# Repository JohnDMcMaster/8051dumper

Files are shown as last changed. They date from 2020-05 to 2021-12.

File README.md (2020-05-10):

# 8051dumper: Dump ROM contents from unprotected 8051 series processors.

This board and firmware allow the mask-programmed ROM contents to be dumped from
[Intel 8051 processors](https://en.wikipedia.org/wiki/Intel_MCS-51) and
derivatives/clones which do not include ROM readout protection mechanisms.

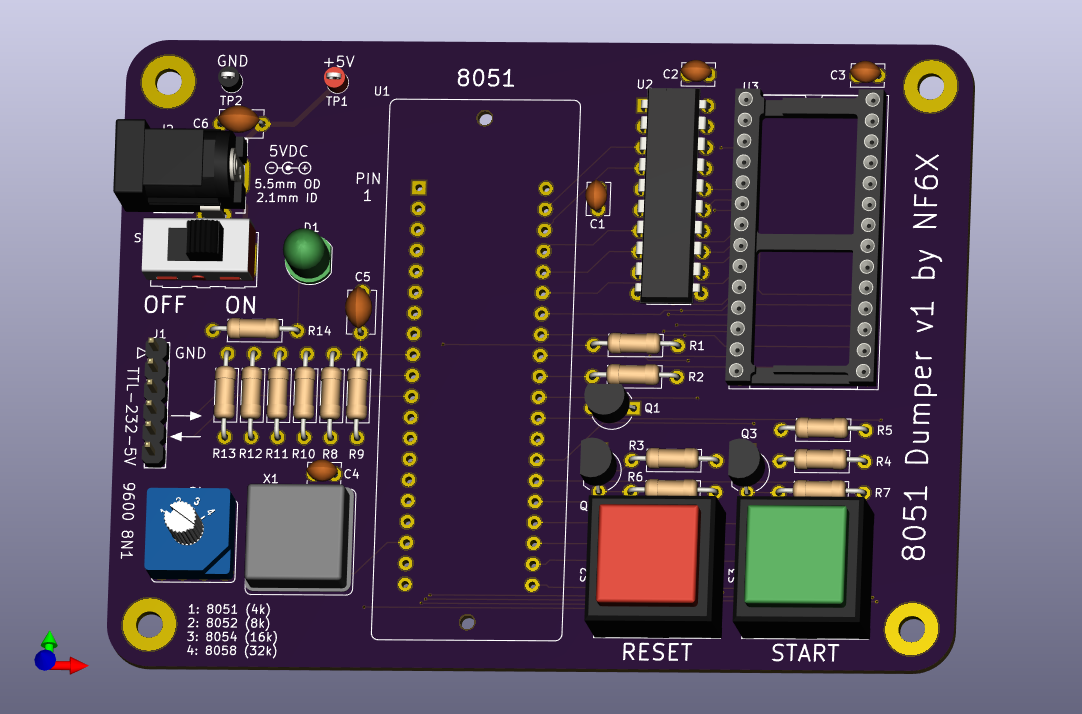
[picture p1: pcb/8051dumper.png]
8051dumper Render


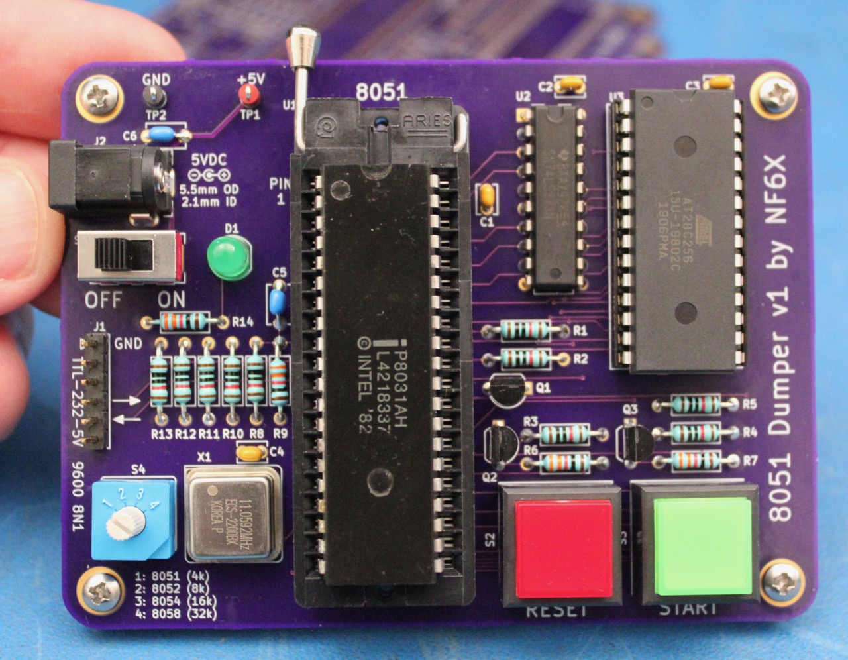
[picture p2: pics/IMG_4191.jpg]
First assembled 8051dumper board, with 8031 standing in for an 8051


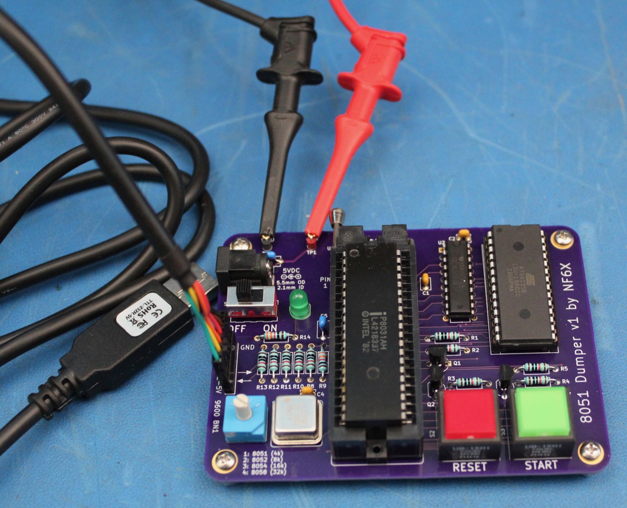
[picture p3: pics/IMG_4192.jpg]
8051dumper board with FTDI TTL-232R-5V cable connected, and power supplied with clip leads


## Description

I wanted to dump out the firmware from the internal mask ROM of a Signetics
SCN8051H microcontroller in an ailing Micropolis 1325 (AKA DEC RD53-A) hard disk
drive. None of my programmers are able to do that, but there's a tricky way to
get early 8051 microcontrollers to dump out their own firmware. I made this
board to do it... and over-engineered the heck out of it, because why not! This
technique has been around for a long time. I didn't invent it. I just made this
board because I'd rather lay out a board than wire up stuff on a breadboard.

The 8051 has a pin called EA\# which tells it whether to fetch code from its
internal ROM (which is programmed at the metal mask layer at chip fabrication
time) or an external ROM. The trick is to put the 8051 into a circuit which
initially pulls EA\# low, so that the 8051 will boot from an external ROM with
our dumper code in it. That code immediately jumps out of the 4k address range
that is mapped to internal ROM when EA\# is high, and then uses a GPIO pin to
pull its own EA\# pin high and re-enable the internal mask ROM. At that point,
the 8051 conveniently fetches program memory accesses in the 0x0000-0x0FFF range
from the internal ROM, and fetches program memory accesses outside that range
from our external ROM. The special dumper code on our external ROM can then use
the MOVC function to read internal ROM bytes, and then dump them out somehow
(such as with the built-in serial port).

The 8052, 8054 and 8058 chips have larger internal ROM spaces, but otherwise
work the same way. Just for the heck of it, I put a knob on this board to tell
its firmware how much of the internal ROM space it should try to dump.

Later 8051 derivatives added features to prevent dumping their internal ROMs
easily, sunce as simply latching EA\# at reset time so that changing it later
doesn't do anything. This board can't work with any of those. It's only intended
to work with original Intel 8051 microcontrollers and exactl clones whose EA\#
pins behave the same way.

## Building the Board

You're on your own for assembling the board. You will need to program the
board's firmware into an AT28C256 (or plug-in equivalent) 32k x 8 (E(E))PROM.
Use the `firmware/8051dumper_filled.hex` image. This image contains the
necessary firmware for the 8051dumper board, with its unused areas filled with a
recognizable pattern to help you identify whether any given device under test is
dumping internal or external ROM contents.

## Using the Board

This board requires an external source of clean, regulated 5 VDC power, and some
sort of asynchronous serial interface with 5V TTL/CMOS signal levels. An FTDI
TTL-232R-5V cable can be pluged right into the header, or you can use clip
leads. The silkscreen markings identify the ground pin and the two data pins.

**There is no reverse-polarity protection, power regulation, or overvoltage protection on this board.** You need to connect the power correctly, or you will fry stuff. You can supply power through either the barrel jack or with clip leads
connected to the two test points.

Set your serial interface for 9600 baud, 8 data bits, no parity, and no flow
control. Use a terminal emulator or any other suitable software which can
capture the 9600 baud stream from 8051dumper.

Always make sure that the power switch is **OFF** before installing or removing
a device under test from 8051dumper.

If all goes well, when you turn on the board with a working [8051 (or other
MCS-51 series)](https://en.wikipedia.org/wiki/Intel_MCS-51) microcontroller
installed, the green START button will begin blinking and the serial port will
spit out `8051dumper v1.0 by NF6X`. If that doesn't happen at power-on, try
pressing the red RESET button to reset the microcontroller manually. If it still
doesn't happen, start debugging. Maybe the socket isn't making good contact?
Maybe, well, literally anything else has gone wrong?

Once the green START button is blinking, set the knob to the appropriate ROM
size and then press the green START button to begin the dump. While the dump is
in progress, the red RESET button will flash rapidly. When the dump is done, the
red RESET button will go dark and the green START button will light up. Now you
can turn off the board, or press RESET to do it all over again.

The 8051dumper output is in [Intel hex](https://en.wikipedia.org/wiki/Intel_HEX)
format. If you try dumping beyond the end of the internal ROM, or if you try
dumping from a device which latches EA\# at reset time, then some or all of the
output will be from the 8051dumper's own external ROM instead of the device
under test's internal ROM. To help you indentify when this happens, the unused
spaces of 8051dumper's ROM are filled with a pattern which is recognizable in
either hexadecimal or ASCII representations, and repeats every 16 bytes:

* Address (2 bytes)
* 0x00
* 0x80
* 0x51
* 0x00
* "8051dumper"

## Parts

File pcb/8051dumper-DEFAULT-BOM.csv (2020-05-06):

MANUFACTURER | PARTNUM | QTY | REFS | IPN | VALUE | DESCRIPTION | FOOTPRINT | ALTERNATES
Aries | 40-6554-10 | 1 | U1 | TBD | 8051 |  | Package_DIP:DIP-40_W15.24mm_ZIF_Socket_Aries_40-6554-10
CK | 1101M2S3CQE2 | 1 | S1 | TBD | CK_1101M2S3CQE2 | SPDT slide switch, ON-ON | Button_Switch_THT:SW_CK_1101M2S3CQE2
CUI | PJ-050AH | 1 | J2 | TBD | CUI_PJ-050AH | DC Barrel Jack, 5.5mm OD x 2.1mm ID, through hole, w/ switch | Connector_BarrelJack:BarrelJack_Horizontal_CUI_PJ-050AH
Copal | S-2150 | 1 | S4 | TBD | Copal_S-2150 | Rotary switch, 4-position DIP 1P4T | Button_Switch_THT:Copal_S-2150
ECS | ECS-2200BX-110.5 | 1 | X1 | TBD | 11.0592 MHz | Crystal Clock Oscillator, DIP8-style metal package | Oscillator:Oscillator_DIP-8
Keystone | 5000 | 1 | TP1 | TBD | TestPoint_Mini_Red | Test point, 19x19mm 0.75x0.75in | TestPoint:TestPoint_Keystone_5000
Keystone | 5001 | 1 | TP2 | TBD | TestPoint_Mini_Black | Test point, 19x19mm 0.75x0.75in | TestPoint:TestPoint_Keystone_5001
Kingbright | WP7113GD | 1 | D1 | TBD | WP7113GD | Light emitting diode | LED_THT:LED_D5.0mm_Green_Kingbright_WP7113
Microchip | AT28C256-15PU | 1 | U3 | TBD | AT28C256-15PU |  | Package_DIP:DIP-28_W15.24mm_Socket
NKK | UB15SKG035C-CC | 1 | S2 | TBD | NKK_UB15SKG035C-CC | Momentary button, SPDT, red LED, square red lens | Button_Switch_THT:SW_NKK_UB15SKG035C-CC
NKK | UB15SKG035F-FF | 1 | S3 | TBD | NKK_UB15SKG035F-FF | Momentary button, SPDT, green LED, square green lens | Button_Switch_THT:SW_NKK_UB15SKG035F-FF
ON Semiconductor | 2N3906TF | 3 | Q1 Q2 Q3 | TBD | 2N3906 | PNP transistor, TO-92, 2N3906 | Package_TO_SOT_THT:TO-92_Inline_Wide
Stackpole | RNF14FTD10K0 | 10 | R1 R2 R3 R4 R5 R8 R10 R11 R12 R13 | TBD | 10k | Resistor | Resistor_THT:R_Axial_DIN0207_L6.3mm_D2.5mm_P10.16mm_Horizontal
Stackpole | RNF14FTD332R | 4 | R6 R7 R9 R14 | TBD | 332 | Resistor | Resistor_THT:R_Axial_DIN0207_L6.3mm_D2.5mm_P10.16mm_Horizontal
Sullins | PBC06SAAN | 1 | J1 | TBD | TTL-232R-5V | Header for FTDI TTL-232R or equivalent | Connector_PinHeader_2.54mm:PinHeader_1x6_P2.54mm_Vertical_Unshrouded
TDK | FG24X7R1A106KRT06 | 2 | C5 C6 | TBD | 10uF | Unpolarized capacitor | Capacitor_THT:C_Disc_D5.1mm_W3.2mm_P5.00mm
TI | SN74LS373N | 1 | U2 | TBD | SN74LS373N | 8-bit Latch, 3-state outputs | Package_DIP:DIP-20_W7.62mm
Vishay | K104K10X7RF5UL2 | 4 | C1 C2 C3 C4 | TBD | 0.1uF | Unpolarized capacitor | Capacitor_THT:C_Disc_D3.8mm_W2.6mm_P2.50mm

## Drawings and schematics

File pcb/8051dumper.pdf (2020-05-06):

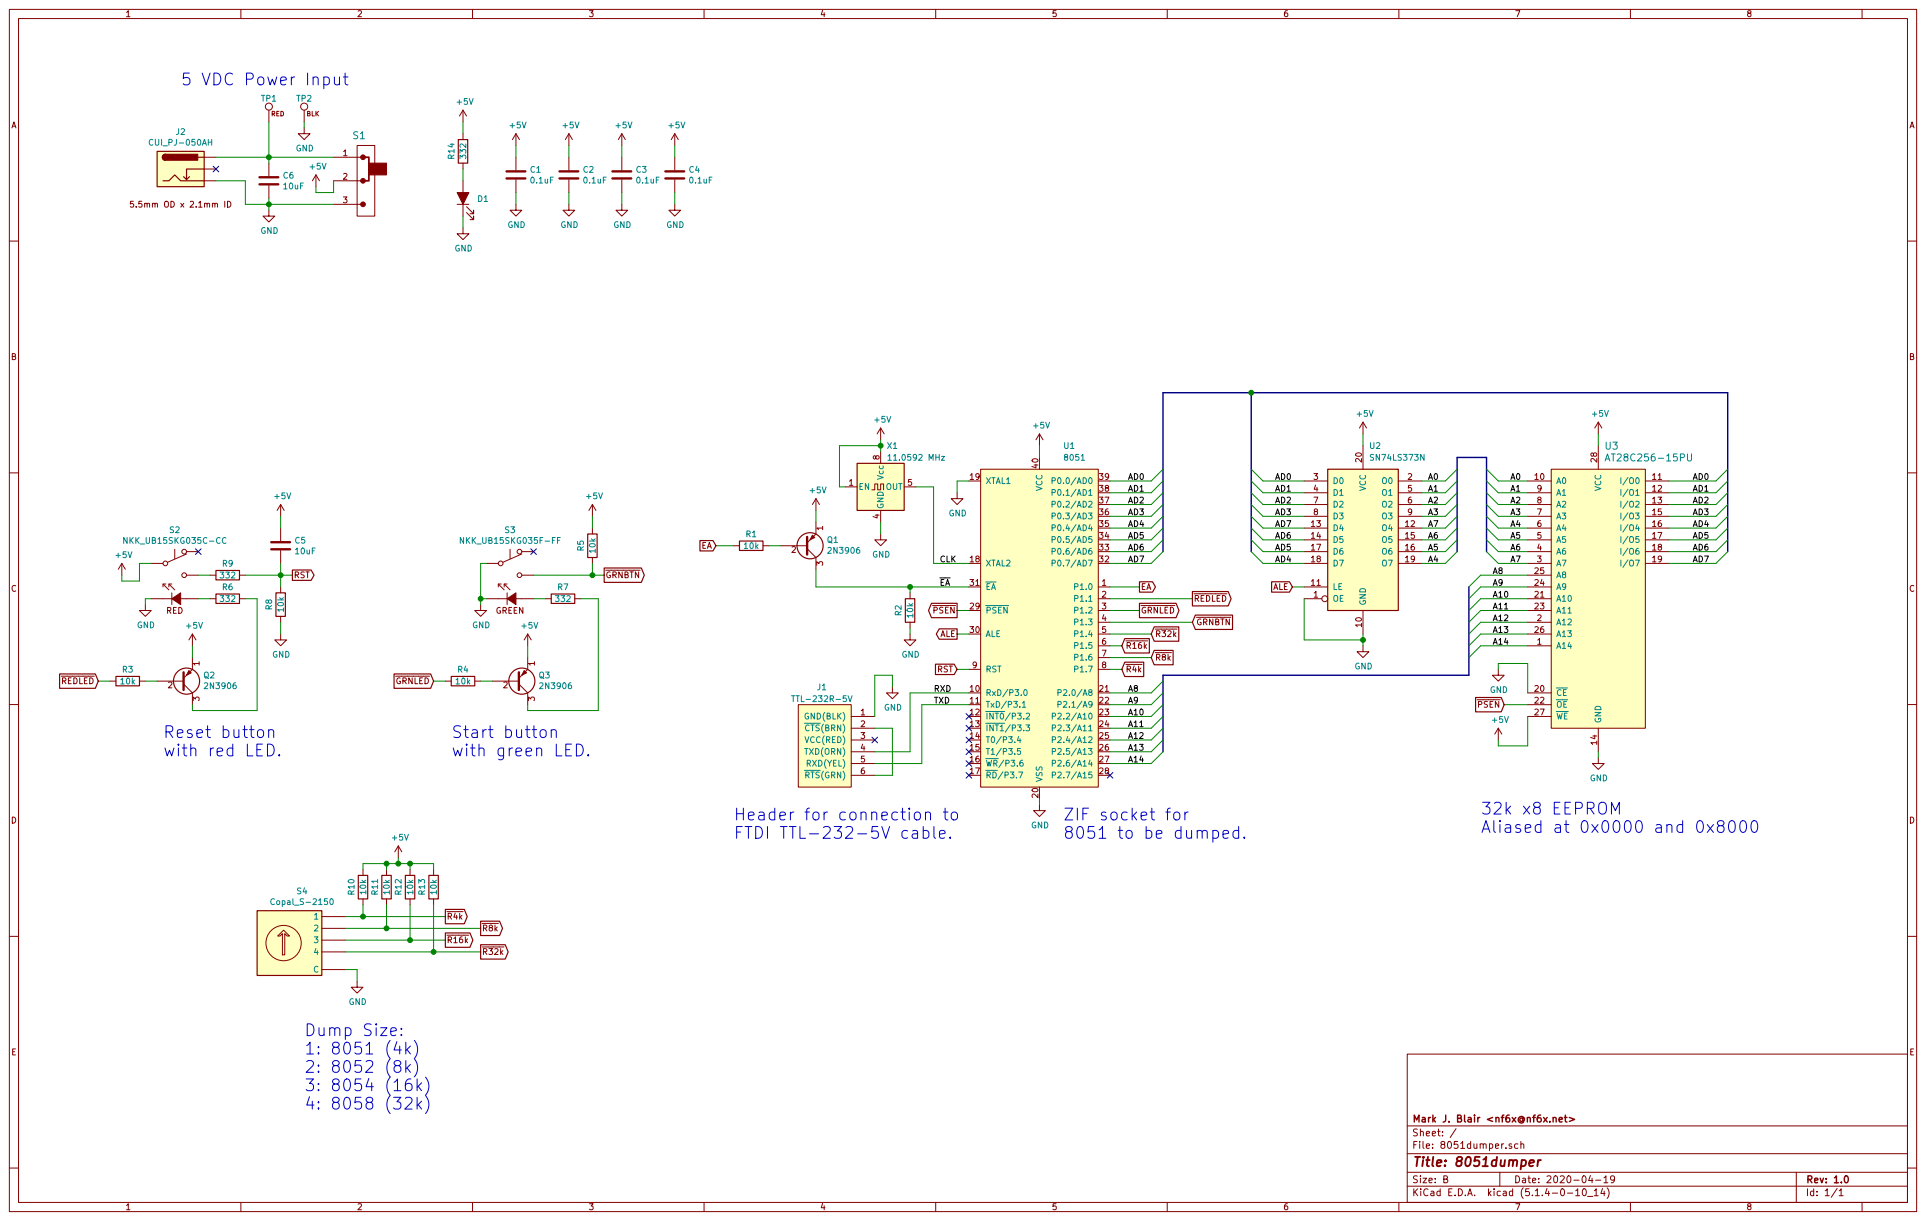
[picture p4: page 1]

Header for connection to
FTDI TTL-232-5V cable.

File: 8051dumper.sch Sheet: / Mark J. Blair <nf6x@nf6x.net>

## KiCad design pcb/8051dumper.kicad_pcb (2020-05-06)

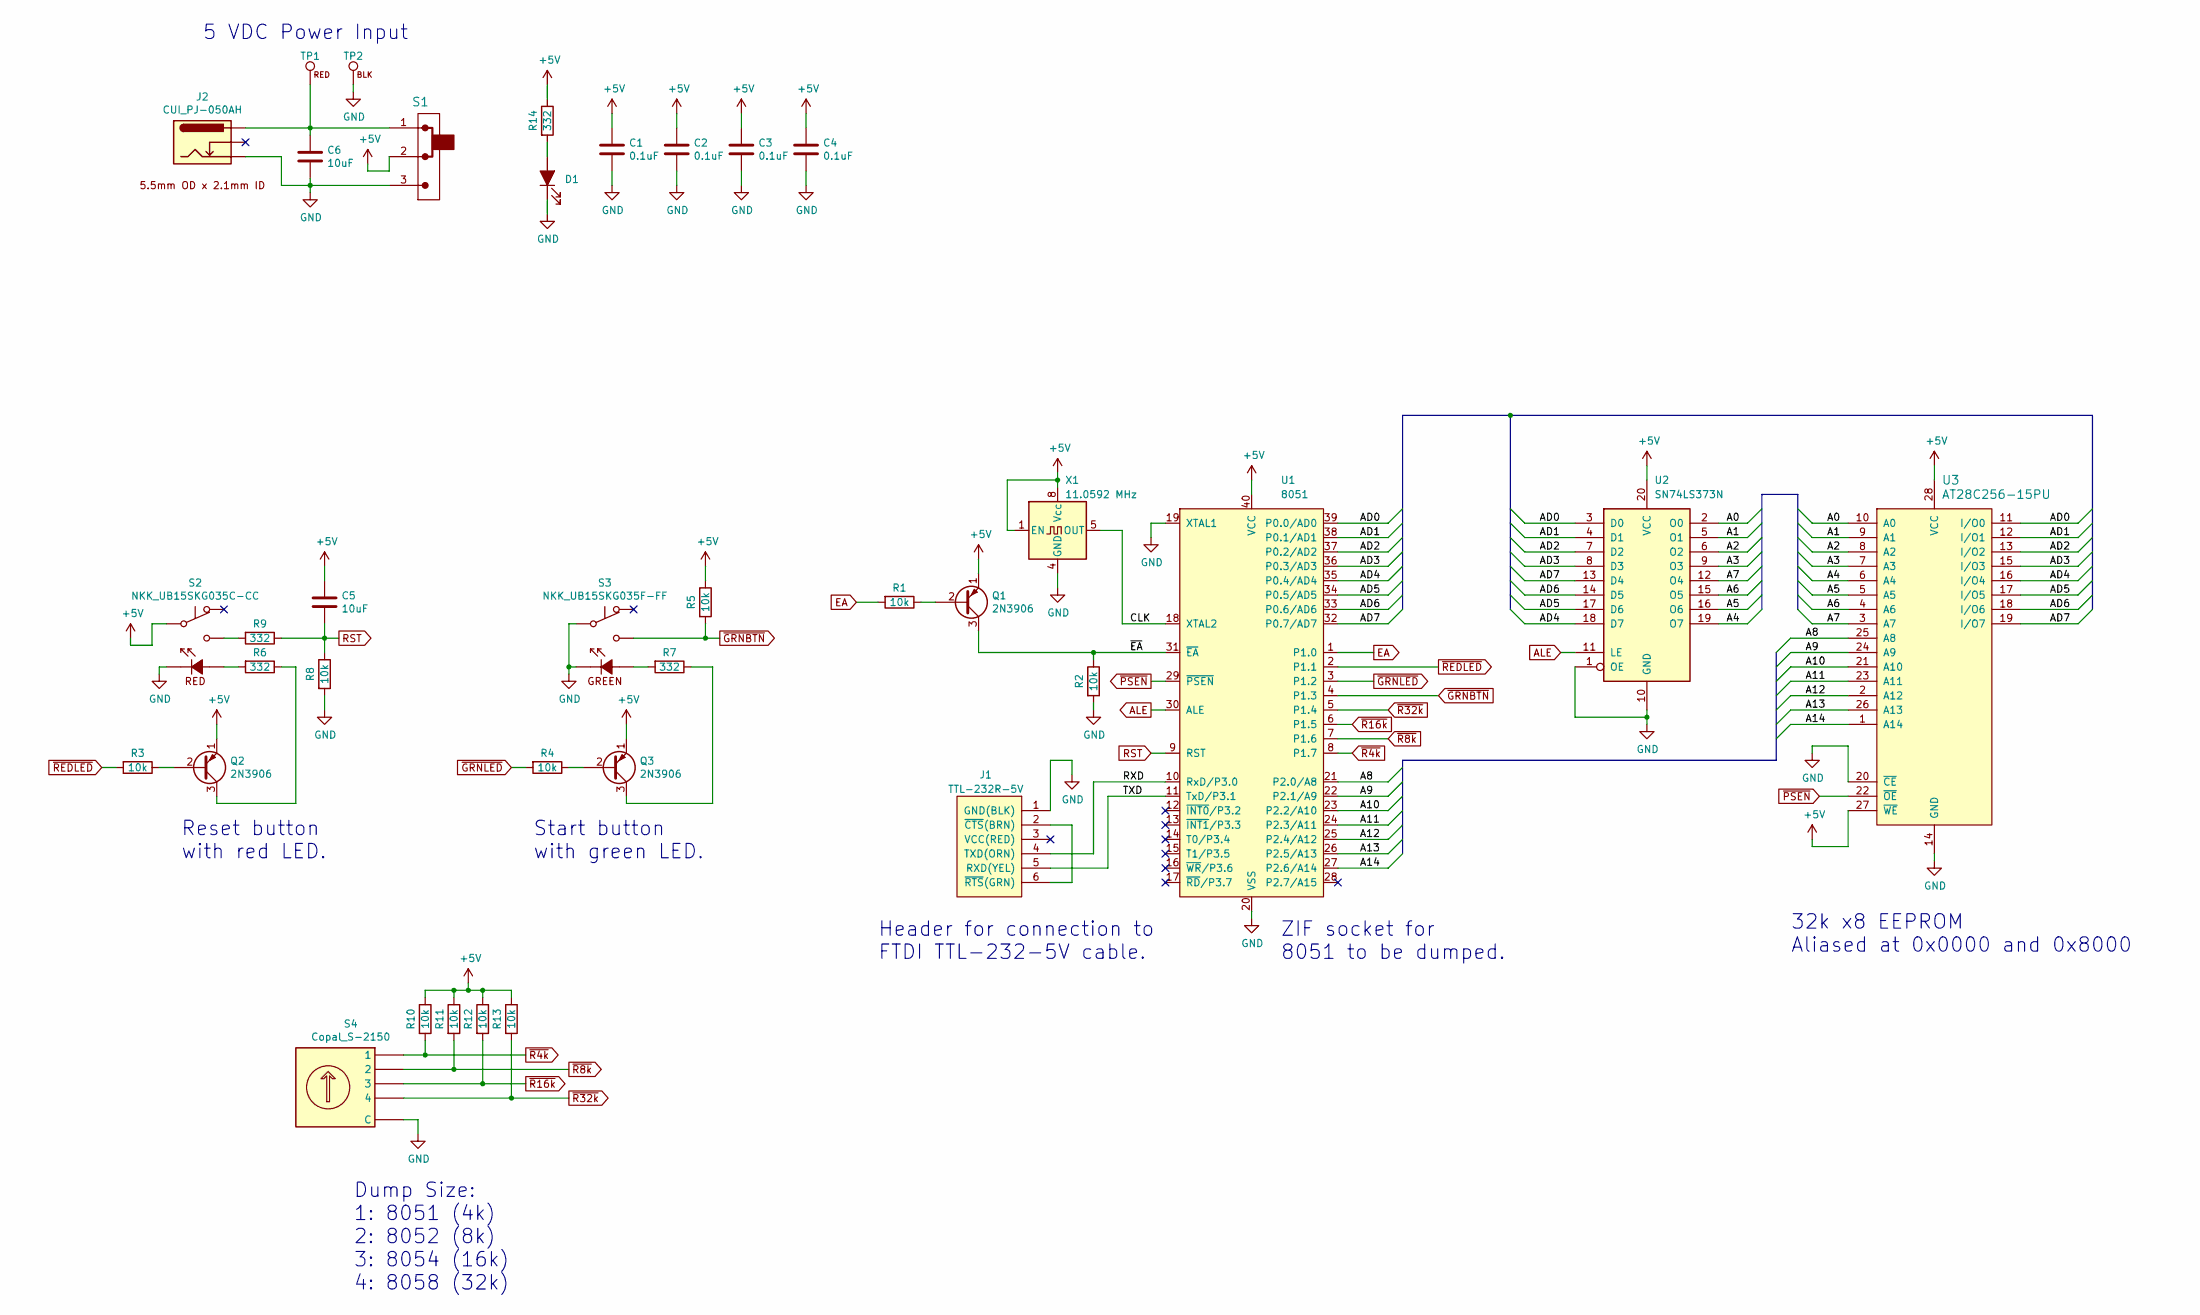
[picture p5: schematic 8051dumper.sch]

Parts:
C1, C2, C3, C4: 0.1uF; C_Disc_D3.8mm_W2.6mm_P2.50mm; MPN Vishay:K104K10X7RF5UL2
C5, C6: 10uF; C_Disc_D5.1mm_W3.2mm_P5.00mm; MPN TDK:FG24X7R1A106KRT06
D1: WP7113GD; LED_D5.0mm_Green_Kingbright_WP7113; MPN Kingbright:WP7113GD
J1: TTL-232R-5V; PinHeader_1x6_P2.54mm_Vertical_Unshrouded; MPN Sullins:PBC06SAAN
J2: CUI_PJ-050AH; BarrelJack_Horizontal_CUI_PJ-050AH; MPN CUI:PJ-050AH
Q1, Q2, Q3: 2N3906; TO-92_Inline_Wide; MPN ON Semiconductor:2N3906TF
R1, R2, R3, R4, R5, R8, R10, R11, R12, R13: 10k; R_Axial_DIN0207_L6.3mm_D2.5mm_P10.16mm_Horizontal; MPN Stackpole:RNF14FTD10K0
R6, R7, R9, R14: 332; R_Axial_DIN0207_L6.3mm_D2.5mm_P10.16mm_Horizontal; MPN Stackpole:RNF14FTD332R
S1: CK_1101M2S3CQE2; SW_CK_1101M2S3CQE2; MPN CK:1101M2S3CQE2
S2: NKK_UB15SKG035C-CC; SW_NKK_UB15SKG035C-CC; MPN NKK:UB15SKG035C-CC
S3: NKK_UB15SKG035F-FF; SW_NKK_UB15SKG035F-FF; MPN NKK:UB15SKG035F-FF
S4: Copal_S-2150; MPN Copal:S-2150
TP1: TestPoint_Mini_Red; TestPoint_Keystone_5000; MPN Keystone:5000
TP2: TestPoint_Mini_Black; TestPoint_Keystone_5001; MPN Keystone:5001
U1: 8051; DIP-40_W15.24mm_ZIF_Socket_Aries_40-6554-10; MPN Aries:40-6554-10
U2: SN74LS373N; DIP-20_W7.62mm; MPN TI:SN74LS373N
U3: AT28C256-15PU; DIP-28_W15.24mm_Socket; MPN Microchip:AT28C256-15PU
X1: 11.0592 MHz; Oscillator_DIP-8; MPN ECS:ECS-2200BX-110.5

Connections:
+5V: C1.1, C2.1, C3.1, C4.1, C5.1, Q1.1 (E), Q2.1 (E), Q3.1 (E), R5.1, R10.1, R11.1, R12.1, R13.1, R14.1, S1.2, S2.1 (COM), U1.40 (VCC), U2.20 (VCC), U3.27 (~WE), U3.28 (VCC), X1.1 (EN), X1.8 (Vcc)
/A0: U2.2 (O0), U3.10 (A0)
/A1: U2.5 (O1), U3.9 (A1)
/A2: U2.6 (O2), U3.8 (A2)
/A3: U2.9 (O3), U3.7 (A3)
/A4: U2.19 (O7), U3.6 (A4)
/A5: U2.16 (O6), U3.5 (A5)
/A6: U2.15 (O5), U3.4 (A6)
/A7: U2.12 (O4), U3.3 (A7)
/A8: U1.21 (P2.0/A8), U3.25 (A8)
/A9: U1.22 (P2.1/A9), U3.24 (A9)
/A10: U1.23 (P2.2/A10), U3.21 (A10)
/A11: U1.24 (P2.3/A11), U3.23 (A11)
/A12: U1.25 (P2.4/A12), U3.2 (A12)
/A13: U1.26 (P2.5/A13), U3.26 (A13)
/A14: U1.27 (P2.6/A14), U3.1 (A14)
/AD0: U1.39 (P0.0/AD0), U2.3 (D0), U3.11 (I/O0)
/AD1: U1.38 (P0.1/AD1), U2.4 (D1), U3.12 (I/O1)
/AD2: U1.37 (P0.2/AD2), U2.7 (D2), U3.13 (I/O2)
/AD3: U1.36 (P0.3/AD3), U2.8 (D3), U3.15 (I/O3)
/AD4: U1.35 (P0.4/AD4), U2.18 (D7), U3.16 (I/O4)
/AD5: U1.34 (P0.5/AD5), U2.17 (D6), U3.17 (I/O5)
/AD6: U1.33 (P0.6/AD6), U2.14 (D5), U3.18 (I/O6)
/AD7: U1.32 (P0.7/AD7), U2.13 (D4), U3.19 (I/O7)
/CLK: U1.18 (XTAL2), X1.5 (OUT)
/RXD: J1.4 (TXD(ORN)), U1.10 (RxD/P3.0)
/TXD: J1.5 (RXD(YEL)), U1.11 (TxD/P3.1)
/~EA: Q1.3 (C), R2.1, U1.31 (~EA)
ALE: U1.30 (ALE), U2.11 (LE)
EA: R1.2, U1.1 (P1.0)
GND: C1.2, C2.2, C3.2, C4.2, C6.2, D1.1 (K), J1.1 (GND(BLK)), J2.2, R2.2, R8.2, S1.3, S2.L- (K), S3.1 (COM), S3.L- (K), S4.C, TP2.1, U1.19 (XTAL1), U1.20 (VSS), U2.1 (OE), U2.10 (GND), U3.14 (GND), U3.20 (~CE), X1.4 (GND)
unnamed: C6.1, J2.1, S1.1, TP1.1
unnamed: D1.2 (A), R14.2
unnamed: J1.2 (~CTS~(BRN)), J1.6 (~RTS~(GRN))
unnamed: Q1.2 (B), R1.1
unnamed: Q2.2 (B), R3.1
unnamed: Q2.3 (C), R6.1
unnamed: Q3.2 (B), R4.1
unnamed: Q3.3 (C), R7.1
unnamed: R6.2, S2.L+ (A)
unnamed: R7.2, S3.L+ (A)
unnamed: R9.2, S2.2 (NO)
RST: C5.2, R8.1, R9.1, U1.9 (RST)
~GRNBTN: R5.2, S3.2 (NO), U1.4 (P1.3)
~GRNLED: R4.2, U1.3 (P1.2)
~PSEN: U1.29 (~PSEN), U3.22 (~OE)
~R4k: R10.2, S4.1, U1.8 (P1.7)
~R8k: R11.2, S4.2, U1.7 (P1.6)
~R16k: R12.2, S4.3, U1.6 (P1.5)
~R32k: R13.2, S4.4, U1.5 (P1.4)
~REDLED: R3.2, U1.2 (P1.1)

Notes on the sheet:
Header for connection to FTDI TTL-232-5V cable.
Reset button with red LED.
Start button with green LED.
ZIF socket for 8051 to be dumped.
5 VDC Power Input
Dump Size: 1: 8051 (4k) 2: 8052 (8k) 3: 8054 (16k) 4: 8058 (32k)
32k x8 EEPROM Aliased at 0x0000 and 0x8000

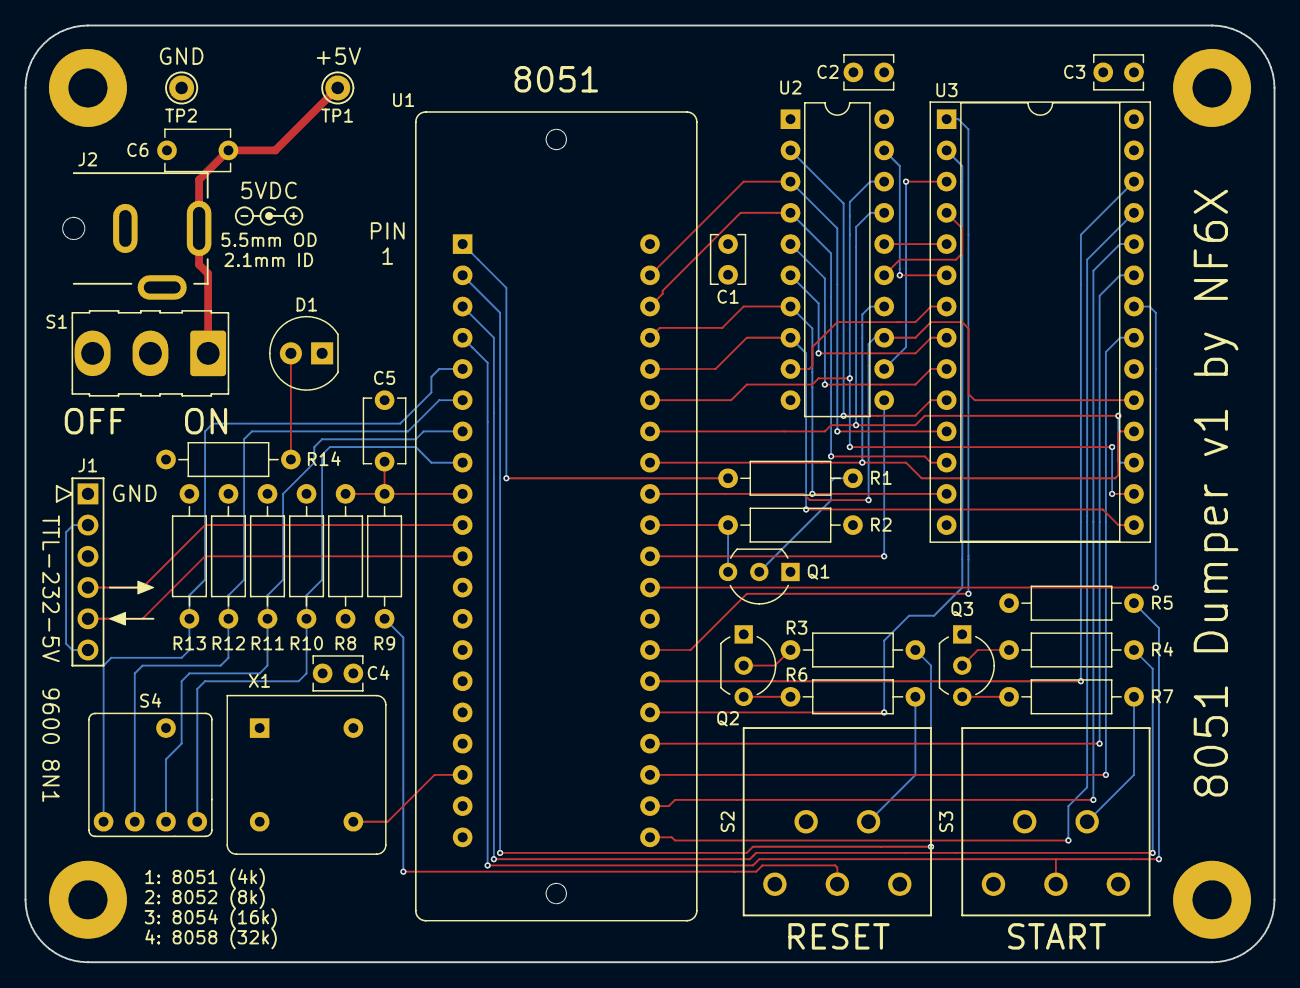
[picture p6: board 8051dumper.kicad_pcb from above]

Board: 4 copper layers, 101.6 x 76.2 mm, 36 parts (0 on the bottom side), 51 nets.

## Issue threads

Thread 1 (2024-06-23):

Question re: BOM

snhirsch, 2024-06-23:
Your BOM calls out all resistors as 1% parts.  Is anything in the circuit critical enough to require precision parts?

I'm also curious about the need for C5 and C6 to be non-polarized.  From looking at the schematic it appears that tantalum or electrolytic parts would be fine.

Can you clarify?  Thanks.

JohnDMcMaster, 2024-07-01:
Hi there! This is a fork of another's project. Please ask the question here: https://gitlab.com/NF6X_Retrocomputing/8051dumper

snhirsch, 2024-07-02:
Ah - thanks, John.  Did you introduce mods to the hardware, software, both?  Just curious.

Closed 2024-07-01.

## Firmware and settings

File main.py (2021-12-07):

#!/usr/bin/env python3

import argparse
import serial
import pexpect.spawnbase
import os
import time
import platform
import subprocess

class NoSuchLine(Exception):
    pass


class BadCommand(Exception):
    pass


class Timeout(Exception):
    pass


def default_port():
    '''Try to guess the serial port, if we can find a reasonable guess'''
    if platform.system() == "Linux":
        return "/dev/ttyUSB0"
    else:
        return None

class SerialExpect(pexpect.spawnbase.SpawnBase):
    '''A pexpect class that works through a serial.Serial instance.
       This is necessary for compatibility with Windows. It is basically
       a pexpect.fdpexpect, except for serial.Serial, not file descriptors.
    '''
    def __init__(self,
                 ser,
                 args=None,
                 timeout=30,
                 maxread=2000,
                 searchwindowsize=None,
                 logfile=None,
                 encoding=None,
                 codec_errors='strict',
                 use_poll=False):
        self.ser = ser
        if not isinstance(ser, serial.Serial):
            raise Exception(
                'The ser argument is not a serial.Serial instance.')
        self.args = None
        self.command = None
        pexpect.spawnbase.SpawnBase.__init__(self,
                                             timeout,
                                             maxread,
                                             searchwindowsize,
                                             logfile,
                                             encoding=encoding,
                                             codec_errors=codec_errors)
        self.child_fd = None
        self.own_fd = False
        self.closed = False
        self.name = ser.name
        self.use_poll = use_poll

    def close(self):
        self.flush()
        self.ser.close()
        self.closed = True

    def flush(self):
        self.ser.flush()

    def isalive(self):
        return not self.closed

    def terminate(self, force=False):
        raise Exception('This method is not valid for serial objects')

    def send(self, s):
        s = self._coerce_send_string(s)
        self._log(s, 'send')
        b = self._encoder.encode(s, final=False)
        self.ser.write(b)

    def sendline(self, s):
        s = self._coerce_send_string(s)
        return self.send(s + self.linesep)

    def write(self, s):
        b = self._encoder.encode(s, final=False)
        self.ser.write(b)

    def writelines(self, sequence):
        for s in sequence:
            self.write(s)

    def read(self, n):
        raise Exception()

    def read_nonblocking(self, size=1, timeout=None):
        s = self.ser.read(size)
        s = self._decoder.decode(s, final=False)
        self._log(s, 'read')
        if 0 and s:
            print("read: ", s)
            print(type(s))
        return s

def ihex2bin(ihex):
    hex_fn = "/tmp/8051dumper_tmp.hex"
    bin_fn = "/tmp/8051dumper_tmp.bin"
    try:
        open(hex_fn, "w").write(ihex)
        subprocess.check_call("objcopy --input-target=ihex --output-target=binary /tmp/8051dumper_tmp.hex /tmp/8051dumper_tmp.bin", shell=True)
        ret = open("/tmp/8051dumper_tmp.bin", "rb").read()
    finally:
        try:
            os.unlink(hex_fn)
        except:
            pass
        try:
            os.unlink(bin_fn)
        except:
            pass
    return ret


class Dumper8051:

    def __init__(self, port=None, verbose=None):
        self.timeout = 3.0
        if port is None:
            port = default_port()
            if port is None:
                raise Exception("Failed to find a serial port")
        if verbose is None:
            verbose = os.getenv("VERBOSE", "N") == "Y"
        self.verbose = verbose
        self.verbose and print("port: %s" % port)
        self.ser = serial.Serial(port,
                                 timeout=0,
                                 baudrate=9600,
                                 writeTimeout=0)
        if 0:
            while True:
                buf = self.ser.read()
                if buf:
                    print(buf)
        self.e = SerialExpect(self.ser, encoding="ascii")
        # Make sure nothing is buffered
        self.e.flush()
        self.flushInput()


    def flushInput(self):
        # Try to get rid of previous command in progress, if any
        tlast = time.time()
        while time.time() - tlast < 0.1:
            buf = self.ser.read(1024)
            if buf:
                tlast = time.time()

        self.ser.flushInput()

    def expectb(self, b, timeout=None):
        if timeout is None:
            timeout = self.timeout
        self.e.expect(b, timeout=timeout)
        return self.e.before

    def expecta(self, s, timeout=None):
        if timeout is None:
            timeout = self.timeout
        self.e.expect(bytearray(s, "ascii"), timeout=timeout)
        return self.e.before

    def readline(self, timeout=3.0):
        ret = ""
        tstart = time.time()
        while True:
            if time.time() - tstart > timeout:
                raise Timeout()
            c = self.e.read_nonblocking()
            if not c:
                continue
            if c == '\n':
                return ret
            tstart = time.time()
            ret += c

    def wait_reset(self, timeout=None):
        if timeout is None:
            timeout = 30.0
        while True:
            try:
                # self.expectb("8051dumper v1.0 by NF6X", timeout=timeout)
                l = self.readline(timeout=timeout)
                if "8051dumper v1.0 by NF6X" in l:
                    return
            except UnicodeDecodeError:
                print("WARNING: read error")

    def read_ihex(self, button_timeout=None):
        if button_timeout is None:
            button_timeout = 30.0
        print("Press red button to reset")
        self.wait_reset(timeout=button_timeout)
        print("Press green button to start")
        ihex = ""
        timeout = button_timeout
        while True:
            try:
                l = self.readline(timeout=timeout)
            except Timeout:
                if ihex:
                    print("Idle, breaking")
                    break
                else:
                    raise Exception("Timed out finding start")
            if not ihex:
                print("Found first line")
            ihex += l + "\r\n"
            # Chunks should come quickly
            timeout = 1.0
        return ihex

    def read_bin(self, button_timeout=None):
        ihex = self.read_ihex(button_timeout=button_timeout)
        return ihex2bin(ihex)


def run(fn_out, port=None, timeout=None, verbose=False):
    dumper = Dumper8051(port=port, verbose=verbose)
    buff = dumper.read_bin(button_timeout=timeout)
    open(fn_out, "wb").write(buff)


def main():
    parser = argparse.ArgumentParser(description='Decode')
    parser.add_argument('--port', default=None, help='Serial port')
    parser.add_argument('--timeout', default=30.0, help='Timeout in seconds')
    parser.add_argument('--verbose', action="store_true")
    parser.add_argument('fn_out', help='File name out')
    args = parser.parse_args()
    run(fn_out=args.fn_out, port=args.port, timeout=args.timeout, verbose=args.verbose)


if __name__ == "__main__":
    main()

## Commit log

2020-05-06 Initial commit: v1 PCB and first blinky code.
    [8051dumper-DEFAULT-BOM.csv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]
2020-05-08 Add pictures of first assembled board.
